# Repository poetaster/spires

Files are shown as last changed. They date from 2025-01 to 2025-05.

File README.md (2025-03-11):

# spires
Spires is an arpeggiating synth using time of flight sensors to drive one or more digital oscillators. The processor used is either and arduino nano or and LGTBF328P.

Tremello is implemented with a simple LDR. 

## Modes

The default program reproduces the modes. Holding the encoder button depressed and turning choses a mode, in the traditional order Ionian, Dorian, Phrygian, Lydian, Mixolodian, Aeolian, Locrian. Pressing the encoder button in this program changes the root, from C to B. So you can play all the modes in any key.

The remaining programs are composed to selected scales.  The programs:
1. ragas
2. various historical europeans
3. some more exotics (geographical as well as cultural)
4. pentatonics from diverse cultures
5. hexatonics 

In all a bunch of scale material :)

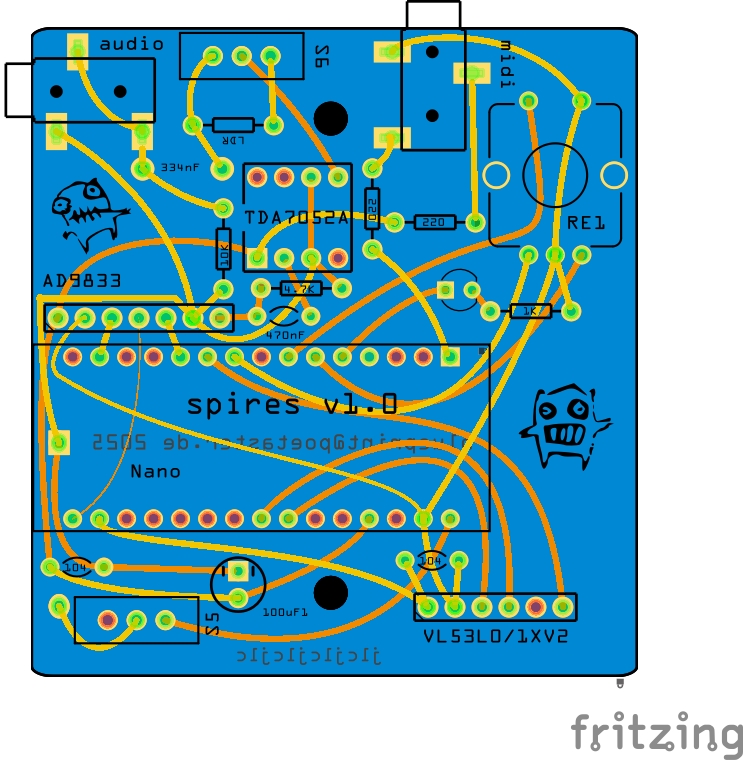
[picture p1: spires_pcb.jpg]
pcb view

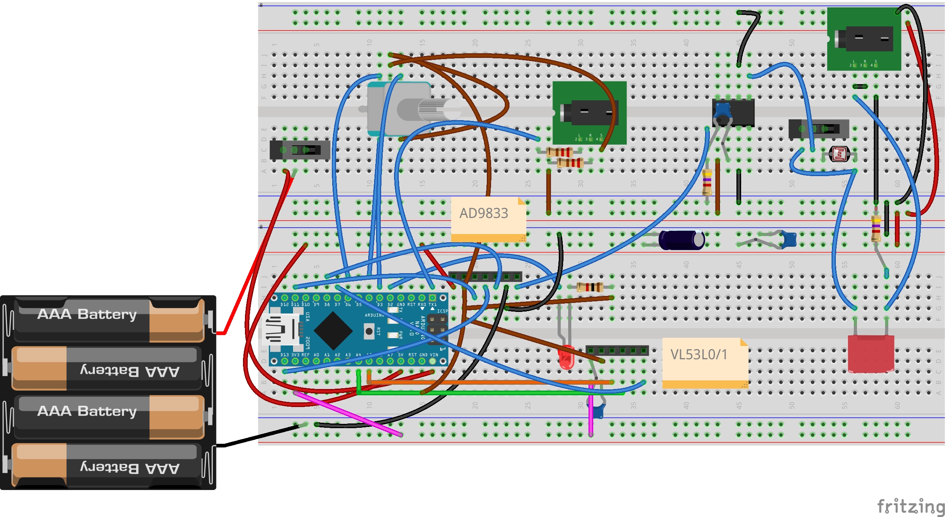
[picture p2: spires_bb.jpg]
breadboard view

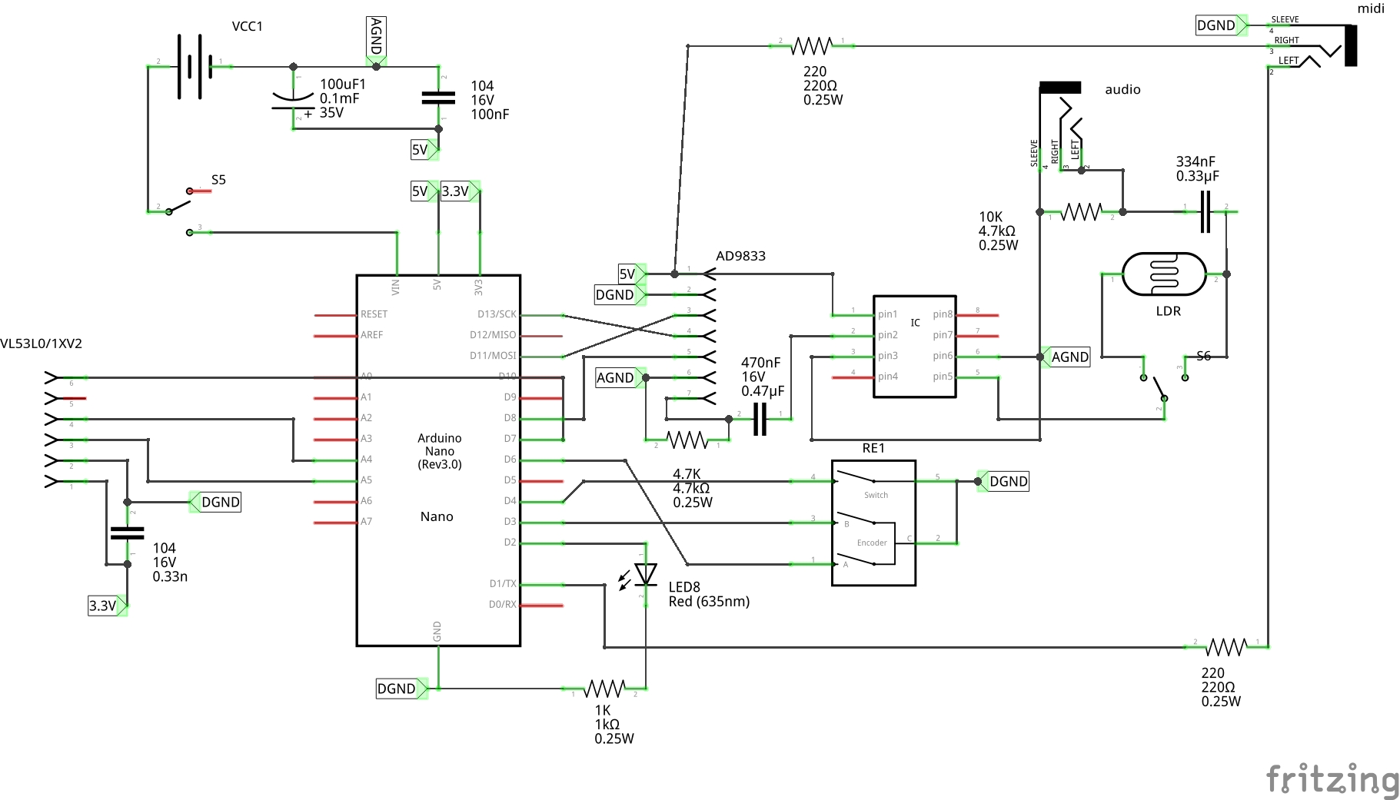
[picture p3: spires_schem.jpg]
schematic view


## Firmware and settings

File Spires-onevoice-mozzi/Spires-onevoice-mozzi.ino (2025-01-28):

/*
  Spires is copyright 2024, Mark Washeim blueprint@poetaster.de
  GPLv3
*/

#include <Wire.h>
#include <VL53L0X.h>
#include <RotaryEncoder.h>

// MOZZI
#define MOZZI_CONTROL_RATE 256  // Hz, powers of 2 are most reliable
#include <Mozzi.h>
#include <Oscil.h>
#include <tables/cos2048_int8.h>  // table for Oscils to play
#include <EventDelay.h>
#include <mozzi_rand.h>
#include <mozzi_midi.h>
#include <Smooth.h>
// audio oscils

Oscil<COS2048_NUM_CELLS, MOZZI_AUDIO_RATE> aCarrier(COS2048_DATA);
Oscil<COS2048_NUM_CELLS, MOZZI_AUDIO_RATE> aModulator(COS2048_DATA);
Oscil<COS2048_NUM_CELLS, MOZZI_AUDIO_RATE> aModDepth(COS2048_DATA);

// for scheduling note changes in updateControl()
EventDelay kNoteChangeDelay;

UFix<8, 8> ratio;          // unsigned int with 8 integer bits and 8 fractional bits
UFix<24, 8> carrier_freq;  // unsigned long with 24 integer bits and 8 fractional bits

// for random notes
const UFix<7, 0> octave_start_note = 42;

// END MOZZI


bool debug = true;


// on the long ec11 these are swapped A 19, B 18
const int encoderA_pin = 2;
const int encoderB_pin = 3;
const int encoderSW_pin = 5;
// variables for UI state management
int encoder_pos_last = 0;
int encoder_delta = 0;


// encoder
RotaryEncoder encoder(encoderB_pin, encoderA_pin, RotaryEncoder::LatchMode::FOUR3);
void checkEncoderPosition() {
  encoder.tick();   // call tick() to check the state.
}

/* these come from rampart bytebeats */
int enc_offset = 1; // changes direction
int enc_delta; // which direction
//for program switching
int prog = 1;
int bank = 1;
int pb1 = 1;
int pb1total = 8;
int pb2 = 1;
int pb2total = 28;
int pb3 = 1;
int pb3total = 20;

int numProg = 8;



/* AUDIO */
const float ContToFreq[63] PROGMEM = {29.14, 30.87, 32.70, 34.65, 36.71, 38.89, 41.20, 43.65, 46.25, 49.00, 51.91, 55.00,
                                      58.27, 61.74, 65.41, 69.30, 73.42, 77.78, 82.41, 87.31, 92.50, 98.00, 103.83, 110.00,
                                      116.54, 123.47, 130.81, 138.59, 146.83, 155.56, 164.81, 174.61, 185.00, 196.00, 207.65, 220.00,
                                      233.08, 246.94, 261.63, 277.18, 293.66, 311.13, 329.63, 349.23, 369.99, 392.00, 415.30, 440.00,
                                      466.16, 493.88, 523.25, 554.37, 587.33, 622.25, 659.25, 698.46, 739.99, 783.99, 830.61, 880.00,
                                      932.33, 987.77, 1046.50
                                     };
// AD9833 Waveform Module
const int SINE = 0x2000;                    // Define AD9833's waveform register value.
const int SQUARE = 0x2028;                  // When we update the frequency, we need to
const int TRIANGLE = 0x2002;                // define the waveform when we end writing.
const float refFreq = 25000000.0;           // On-board crystal reference frequency
float freq_init1 = 440.0;                    // Initial frequency for Generator 1
float freq_init2 = 442.0;                    // Initial frequency for Generator 2
float freq_target1 = 440.0;                 // Target frequency for Generator 1
float freq_target2 = 442.0;                 // Target frequency for Generator 2
float freq_offset = 1; //4 / 3;

float volume = 1000;  // volume for our machine

// Table with note symbols, used for display
const char *IndexToNote[] = {"C-", "C#", "D-", "D#", "E-", "F-", "F#", "G-", "G#", "A-", "A#", "B-"};

// Tables with frequencies from scales around the world
#include "scales.h"

#define BASE_NOTE_FREQUENCY  16.3516 // C-0, Core of note/cent offset calculations, keep it accurate
// Definition of generated frequency range

signed char note_target = 47; //A-4, 440Hz
#define NOTE_CALCULATION_OFFSET 10 //base note for calculation is C-0, but note table starts from A#0 

float noteIndex;

/* END AUDIO */


// The Arduino pin connected to the XSHUT pin of each sensor.
const uint8_t xshutPins[2] = {6, 7};

int led = 10; // for the vactrol
//  analogReference(DEFAULT);  // 5v

// The number of sensors in your system.
const uint8_t sensorCount = 2;
VL53L0X sensors[sensorCount];

// variables for runtime control
bool up;
bool cont = true;
bool continuous = false;
float lastVol = 99;
float currentDepth = 9;
bool flutter = false;

void setup()
{

  //while (!Serial) {}
  Serial.begin(115200);
  //Wire1.setSDA(14); These are for the pi pico
  //Wire1.setSCL(15);
  //Wire.setSDA(0);
  //Wire.setSCL(1);
  
  Wire.begin();
  Wire.setClock(400000); // use 400 kHz I2C

  
  // setup the sensors
  // Disable/reset all sensors by driving their XSHUT pins low.
  for (uint8_t i = 0; i < sensorCount; i++)
  {
    pinMode(xshutPins[i], OUTPUT);
    digitalWrite(xshutPins[i], LOW);
  }

  // Enable, initialize, and start each sensor, one by one.
  for (uint8_t i = 0; i < sensorCount; i++)
  {
    // Stop driving this sensor's XSHUT low. This should allow the carrier
    // board to pull it high. (We do NOT want to drive XSHUT high since it is
    // not level shifted.) Then wait a bit for the sensor to start up.
    pinMode(xshutPins[i], INPUT);
    delay(10);

    sensors[i].setTimeout(500);
    if (!sensors[i].init())
    {
      Serial.print("Failed to detect and initialize sensor ");
      Serial.println(i);
      while (1);
    }

    // Each sensor must have its address changed to a unique value other than
    // the default of 0x29 (except for the last one, which could be left atSerial.println(freq_init1);
    // the default). To make it simple, we'll just count up from 0x2A.
    sensors[i].setAddress(0x2A + i);
    sensors[i].startContinuous(50);
    sensors[i].setMeasurementTimingBudget(70000); //  adjust this value to move to slower note slurs/jumps

  }
  
  //pinMode(23, OUTPUT); // thi is to switch to PWM pi pico for power to avoid ripple noise
  //digitalWrite(23, HIGH);

  // ENCODER
  pinMode(encoderA_pin, INPUT_PULLUP);
  pinMode(encoderB_pin, INPUT_PULLUP);
  pinMode(5, INPUT_PULLUP);
  attachInterrupt(digitalPinToInterrupt(encoderA_pin), checkEncoderPosition, CHANGE);
  attachInterrupt(digitalPinToInterrupt(encoderB_pin), checkEncoderPosition, CHANGE);
  
  //sensors[1].setSignalRateLimit(0.1);
  // increase laser pulse periods (defaults are 14 and 10 PCLKs)
  // sensors[1].setVcselPulsePeriod(VL53L0X::VcselPeriodPreRange, 18);
  //sensors[1].setVcselPulsePeriod(VL53L0X::VcselPeriodFinalRange, 14);
  //
  //sensors[0].setMeasurementTimingBudget(70000);
  //sensors[1].setMeasurementTimingBudget(70000);
  
  Serial.println(sensors[0].readRangeSingleMillimeters());
  //analogWrite(4, 255);

  // mozzi setup
  ratio = 3;
  kNoteChangeDelay.set(200);  // note duration ms, within resolution of MOZZI_CONTROL_RATE
  aModDepth.setFreq(13.f);    // vary mod depth to highlight am effects
  randSeed();                 // reseed the random generator for different results each time the sketch runs
  startMozzi();

  if (debug) {
    Serial.println("end setup");
  }


}


int steps = 4;

void updateControl() {

  

  // set play mode 0 play 1 edit patterns, 3 FX?
  /*
  if (encoder_push_millis > 0 ) {
    if ((now - encoder_push_millis) > 25 && ! encoder_delta ) {
      if ( !encoder_held ) {
        encoder_held = true;
        display_mode = display_mode+1;
        if ( display_mode > 2) { // switched back to play mode
          display_mode = 0;
          //configure_sequencer();
        }
      }
    }

    if (step_push_millis > 0) { // we're pushing a step key too
      if (encoder_push_millis < step_push_millis) {  // and encoder was pushed first
        //strcpy(seq_info, "saveseq");
      }
    }
  }*/




}

AudioOutput updateAudio() {
  auto mod = UFix<8, 0>(128 + aModulator.next()) * UFix<8, 0>(128 + aModDepth.next());
  return MonoOutput::fromSFix(mod * toSFraction(aCarrier.next()));
}

// second core setup
// second core dedicated to sample processing
void setup1() {
  delay (1000); // wait for main core to start up perhipherals
  
}

// second core calculates samples and sends to DAC
void loop1() {
float temp1;
  int temp2;
  float voltemp;
  Serial.println("Update control");
  if (sensors[0].timeoutOccurred()) {
    Serial.print(" TIMEOUT");
  }

  volume = sensors[0].readRangeContinuousMillimeters();

  Serial.println(volume);
  if (volume < 8190.00) {
    //if (debug )    Serial.println(volume);
    // alwasy adjust volume as fast as possible and don't continue loop until it's finished.
    volume = map(volume, 50, 1300, 255, 1);

    if (volume > 255) volume = 255;
    if (volume < 1 ) volume = 1;
    if (debug )    Serial.println( lastVol);
    //if (debug ) Serial.print(" - ");

    //Tremello(); //
    if (! flutter) {
      //flutter = GlideVolume( volume , lastVol );
    }
    //currentDepth = volume;
    lastVol = volume;
     ratio = volume;
  }

  freq_target2 = sensors[1].readRangeContinuousMillimeters();
  
  if (freq_target2  < 1300 ) {
    if ( ! continuous ) {
      temp2 = int(map(freq_target2, 50, 1300, 28, 0));
    } else {
      temp2 = map(freq_target2, 50, 1300, 780, 420);
    }
    //if (debug) Serial.print("freq:");
    //if (debug )  Serial.println(temp2);
  }

  switch (prog) {
    case 1:
      temp1 = pgm_read_float( &IndexToFreq[temp2 ]);
      break;
    case 2:
      temp1 = pgm_read_float( &BayatiToFreq[temp2 ]);
      break;
    case 3:
      temp1 = pgm_read_float( &nawaAtharToFreq[temp2]);
      break;
    case 4:
      temp1 = pgm_read_float( &farafahzaToFreq[temp2 ]);
      break;
    case 5:
      temp1 = pgm_read_float( &nikrizToFreq[temp2 ]);
      break;
    case 6:
      temp1 = pgm_read_float( &phrygianToFreq[temp2 ]);
      break;
    case 7:
      temp1 = pgm_read_float( &romaMinorToFreq[temp2 ]);
      break;
    case 8:
      temp1 = pgm_read_float( &partch1ToFreq[temp2 ]);
      break;
  }


  // here we either glide up or down
  if ( temp1 < 1600  && temp1 > 30 && continuous == false) {
    if (freq_init1 > temp1) {
      cont = GlideFreq(freq_init1, temp1, false);

    } else if (freq_init1 < temp1) {
      cont = GlideFreq(freq_init1, temp1, true);
    }
    freq_init1 = temp1;
  } else if (temp2 < 800  && temp2 > 100 && continuous == true ) { //&& abs(freq_init1 - temp2) > 5 ) {
    if (freq_init1 > temp2) {
      cont = GlideContinuous(freq_init1, temp2, false);

    } else if (freq_init1 < temp2) {
      cont = GlideContinuous(freq_init1, temp2, true);
    }
    freq_init1 = temp2;
  }


  encoder.tick();
  
  int encoder_pos = encoder.getPosition();
  if ( (encoder_pos != encoder_pos_last )) {
    encoder_delta = encoder_pos - encoder_pos_last;
    prog = constrain(encoder_pos, 1, numProg );
    Serial.println(encoder_pos);
  }

}

void loop()
{
    audioHook();
}

// END LOOP

// Function to glide notes up/down
bool GlideFreq(float from, float too, bool up) {
   Serial.println("Glide");
  //make sure we complete the glides before the loop proceeds
  cont = false;
  if (up) {
    while (from < too) {
      carrier_freq = from;
      auto mod_freq = carrier_freq * ratio;
      aCarrier.setFreq(carrier_freq);
      aModulator.setFreq(mod_freq);
      from = from + 0.3;
      }
  } else {
    while (from > too) {
      carrier_freq = from;
      auto mod_freq = carrier_freq * ratio;
      aCarrier.setFreq(carrier_freq);
      aModulator.setFreq(mod_freq);
      from = from - 0.3;

    }
    // complete since while may exit early

  }


  return true;
}
// Function to glide notes up/down
bool GlideContinuous(float from, float too, bool up) {
  //make sure we complete the glides before the loop proceeds
  cont = false;
  if (up) {
    while (from < too) {
      //AD[0].setFrequency(from);
      //AD[1].setFrequency(from * freq_offset);
      from = from + 0.1;

    }
    // complete since while may exit early
    //AD[0].setFrequency(too);
    //AD[1].setFrequency(too * freq_offset);

  } else {
    while (from > too) {
      //AD[0].setFrequency(from);
      //AD[1].setFrequency(from * freq_offset);
      from = from - 0.1;

    }
    // complete since while may exit early
    //AD[0].setFrequency(too);
    //AD[1].setFrequency(too * freq_offset);
  }
  return true;
}



// Function to glide volume up/down
bool GlideVolume(float from, float too) {
  flutter = true;
  //make sure we complete the glides before the loop proceeds
  float ft = from;

  if (from < too) {
    while (ft < too) {
      //analogWrite(4, from);
      ft = ft + 1;
      //MCP.setValue(from);
      //pot.increase(1);

    }

  } else {
    while (ft > too) {
      //analogWrite(4, from);
      ft = ft - 1;
      //MCP.setValue(from);
      //pot.decrease(1);


    }
  }
  return false;
}
// Function to glide volume up/down
void Tremello() {
  //make sure we complete the glides before the loop proceeds
  if (lastVol < ( 99 - currentDepth) ) {
    lastVol = lastVol + 1;
    //pot.increase(1);

  } else {
    lastVol = lastVol - 1;
    //pot.decrease(1);
  }
  if (debug )    Serial.println( lastVol);
}

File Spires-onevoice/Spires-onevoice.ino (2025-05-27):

/*
  Spires is copyright 2024, Mark Washeim blueprint@poetaster.de
  GPLv3



*/
#include <SPI.h>
#include <Wire.h>
#include <VL53L0X.h>
#include <MIDI.h>
#include <Midier.h>
#include <math.h>
#include <util/crc16.h>
#include "AD9833.h"

// # define ENCODER_DO_NOT_USE_INTERRUPTS
#include <EncoderButton.h>

// some midier setup

MIDI_CREATE_INSTANCE(HardwareSerial, Serial, MIDI);


const midier::Degree scaleDegrees[] = { 1, 2, 3, 4, 5, 6, 7, 8, 9, 10, 11, 12, 13, 14, 15, 16, 17, 18, 19, 20, 21 };
const midier::Note roots[] = {
  midier::Note::C, midier::Note::D,  midier::Note::E, midier::Note::F, midier::Note::G, midier::Note::A, midier::Note::B
};

midier::Mode mode;
int scaleRoot = 0; // start at c, yawn.

int currentMode[21];

void initScales() {
  // iterate over all root notes
  const midier::Mode mode = midier::Mode::Ionian;
  for (auto note : roots)
  {
    // play the major chord
    makeScale(note, mode);
  }
}
void makeScale(midier::Note root, midier::Mode mode) {

  // the root note of the scale
  const midier::Note scaleRoot = root;

  // we are playing ionian mode which is the major scale
  // if you are not familiar with modes, just know that "ionian" is the major scale and "aeolian" is the minor scale
  //const midier::Mode mode = midier::Mode::Ionian;


  for (midier::Degree scaleDegree : scaleDegrees)
  {
    // find out the interval to be added to the root note for this chord degree and chord quality
    const midier::Interval interval = midier::scale::interval(mode, scaleDegree);

    // calculate the note of this chord degree
    const midier::Note note = scaleRoot + interval;
    currentMode[ scaleDegree - 1 ] = midier::midi::number(note, 2);


  }
  //Serial.println();
}


bool debug = false;
// variables for runtime control
bool up;
bool cont = true;
volatile float lastvol = 255;
unsigned int lastPos;
bool continuous = false;
bool sine = true;

// freq to midi
static const uint32_t midi_note_at_zero_volts = 12;
static const float semitones_per_octave = 12.0f;
static const float volts_per_semitone = 1.0f / semitones_per_octave;
static const float a4_frequency = 440.0f;
static const uint32_t a4_midi_note = 69;

int led = 2; // for display led
// default works fine


/*
  Converts a note frequency to the closest corresponding MIDI
  note number.
  Adapted from https://gist.github.com/francoisgeorgy/d155f4aa5e8bd767504c2b43e1ba2902
*/
uint32_t frequency_to_midi_note(float frequency) {
  float note = 69.0f + logf(frequency / a4_frequency) / logf(2.0f) * semitones_per_octave;
  return ceil(note);
}

float midi_note_to_frequency(uint32_t midi_note) {
  float semitones_away_from_a4 = (float)(midi_note) - (float)(a4_midi_note);
  return powf(2.0f, semitones_away_from_a4 / semitones_per_octave) * a4_frequency;
}

int midiChannel = 1;  // Define which MIDI channel to transmit on (1 to 16).


// need to send note offs :)
void allOff() {
  for (int i = 28; i < 90; i++) {
    if ( ! debug) MIDI.sendNoteOff(i, 0, midiChannel);
  }
}


/* signal generator setup */

unsigned int cSpeed = 200000;
//  each device needs its own select pin.
AD9833 AD[1] =
{
  AD9833(8),
  //AD9833(9)
};  //  4 devices.

/* TOF sensor setup */

// The number of sensors in your system.
const uint8_t sensorCount = 1; // original used two. switched to ldr for volume
// The Arduino pin connected to the XSHUT pin of each sensor.
const uint8_t xshutPins[sensorCount] = {7};

VL53L0X sensors[sensorCount];


// encoder setup
// the a and b + the button pin large encoders are 6,5,4
EncoderButton eb1(3, 6, 4);


/* these come from rampart bytebeats */
int encoder_pos_last = 0;
long encoder_delta = 0;
int enc_offset = 1; // changes direction
int enc_delta; // which direction

// program switching ugh, todo
int prog = 0;
int bank = 0;
int pb1 = 0;
int pb1total = 7;
int pb2 = 0;
int pb2total = 6;
int pb3 = 0;
int pb3total = 6;
int pb4 = 0;
int pb4total = 10;
int pb5 = 0;
int pb5total = 6;
int pb6 = 0;
int pb6total = 7;

int numProg = 41;
int numBank = 6;

// we have to slow it down :)
unsigned long startMillis;
unsigned long currentMillis;
const unsigned long period = 95; // this is the frequency change loop delay

int lastNote;

/* led control vars */
int ledState = LOW;
int blinkTotal = 0;
unsigned long previousMillis ; // = millis();
int intervalLength = 0; // we have three different delay times, so we switch on typte

#include "encoder.h"


/* AUDIO */
const float ContToFreq[63] PROGMEM = {29.14, 30.87, 32.70, 34.65, 36.71, 38.89, 41.20, 43.65, 46.25, 49.00, 51.91, 55.00,
                                      58.27, 61.74, 65.41, 69.30, 73.42, 77.78, 82.41, 87.31, 92.50, 98.00, 103.83, 110.00,
                                      116.54, 123.47, 130.81, 138.59, 146.83, 155.56, 164.81, 174.61, 185.00, 196.00, 207.65, 220.00,
                                      233.08, 246.94, 261.63, 277.18, 293.66, 311.13, 329.63, 349.23, 369.99, 392.00, 415.30, 440.00,
                                      466.16, 493.88, 523.25, 554.37, 587.33, 622.25, 659.25, 698.46, 739.99, 783.99, 830.61, 880.00,
                                      932.33, 987.77, 1046.50
                                     };



#define GEN_DATA    11
// AD9833 Waveform Module
const int SINE = 0x2000;                    // Define AD9833's waveform register value.
const int SQUARE = 0x2028;                  // When we update the frequency, we need to
const int TRIANGLE = 0x2002;                // define the waveform when we end writing.
const float refFreq = 25000000.0;           // On-board crystal reference frequency
float freq_init1 = 440.0;                    // Initial frequency for Generator 1
float freq_init2 = 442.0;                    // Initial frequency for Generator 2
float freq_target1 = 440.0;                 // Target frequency for Generator 1
float freq_target2 = 442.0;                 // Target frequency for Generator 2
float freq_offset = 1; //4 / 3;

// Table with note symbols, used for display
const char *IndexToNote[] = {"C-", "C#", "D-", "D#", "E-", "F-", "F#", "G-", "G#", "A-", "A#", "B-"};

// Tables with frequencies from scales around the world
#include "scales.h"

#define BASE_NOTE_FREQUENCY  16.3516 // C-0, Core of note/cent offset calculations, keep it accurate
// Definition of generated frequency range
#define MIN_GENERATED_FREQ  30.0 // Do not change to lower if you like your speakers
#define MAX_GENERATED_FREQ  1000.0
// Definition of binaural generator setting modes
#define MODE_FREQ_FREQ    0
#define MODE_FREQ_OFFSET  1
#define MODE_NOTE_OFFSET  2
#define MODE_SAVE         3

signed char note_target = 47; //A-4, 440Hz
#define NOTE_CALCULATION_OFFSET 10 //base note for calculation is C-0, but note table starts from A#0 

float noteIndex;

/* END AUDIO */
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

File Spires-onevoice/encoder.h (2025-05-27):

/**
   handle encoder button long press event
*/
void onEb1LongPress(EncoderButton& eb) {

  long ecount = eb.longPressCount();
  if ( ecount > 1 ) {
    if (sine == true) {
      AD[0].setWave(AD9833_TRIANGLE);
      sine = false;
      blinkTotal = 2;
      intervalLength = 300;
    } else {
      AD[0].setWave(AD9833_SINE);
      sine = true;
      blinkTotal = 4;
      intervalLength = 300;
    }
  } else {
    allOff();
    AD[0].setFrequency(10.00, 0);     //  A
  }

  if (debug) {
    Serial.print("button1 longPressCount: ");
    Serial.println(sine);
  }
}
/**
   handle encoder turn with  button pressed
   offsets OCR2A
*/
void onEb1PressTurn(EncoderButton& eb) {

  if (debug == false ) allOff();

  enc_delta = eb.increment();

  bank = bank + enc_delta; // freom main class total
  if ( bank > numBank - 1 ) {
    bank = 0;
  } else if ( bank < 0 ) {
    bank = numBank - 1;
  }

  blinkTotal = (bank + 1) * 2;
  intervalLength = 225;

  if (debug) {
    Serial.print("eb1 press inc by: ");
    Serial.println(enc_delta);
    Serial.print("enc_offset is: ");
    Serial.println(enc_offset);
  }
}

/**
   handle encoder turn with  button pressed
*/
void onEb1Clicked(EncoderButton& eb) {

  // if ( debug == false )  MIDI.sendNoteOff(frequency_to_midi_note(lastNote), 0, midiChannel);//allOff();

  // set which bank to select formulas from
  int type = eb.clickCount();

  if (bank == 0 ) {

    scaleRoot += 1;
    if (scaleRoot > 6) scaleRoot = 0;
    blinkTotal = 2;
    intervalLength = 150;
  } else {
    if (type == 1 ) {
      continuous = true;
      cSpeed = 50000;
      blinkTotal = 2;
      intervalLength = 100;
    }
    if (type == 2) {
      continuous = false;
      cSpeed = 200000;
      blinkTotal = 4;
      intervalLength = 100;
    }
  }

  if (debug) {
    Serial.print("bank: ");
    Serial.println(eb.clickCount());
  }
  // displayUpdate();
}



/**
   A function to handle the 'encoder' event without button
*/
void onEb1Encoder(EncoderButton& eb) {

  // turn off midi notes
  //if (debug == false) allOff();

  //displayUpdate();
  enc_delta = eb.increment();

  //prog = prog + enc_delta; // freom main class total

  if (bank == 0)
  {
    pb1 = pb1 + enc_delta;
    if (pb1 > pb1total - 1) {
      pb1 = 0;
    } else if (pb1 < 0) {
      pb1 = pb1total - 1;
    }
    prog = pb1;
  }
  else if (bank == 1) {
    pb2 = pb2 + enc_delta;
    if (pb2 > pb2total - 1) {
      pb2 = 0;
    } else if (pb2 < 0) {
      pb2 = pb2total - 1;
    }
    prog = pb2;
  }
  else if (bank == 2) {
    pb3 = pb3 + enc_delta;
    if (pb3 > pb3total - 1) {
      pb3 = 0;
    } else if (pb3 < 0) {
      pb3 = pb3total - 1;
    }
    prog = pb3;
  }
  else if (bank == 3) {
    pb4 = pb4 + enc_delta;
    if (pb4 > pb4total - 1) {
      pb4 = 0;
    } else if (pb4 < 0) {
      pb4 = pb4total - 1;
    }
    prog = pb4;
  }
  else if (bank == 4) {
    pb5 = pb5 + enc_delta;
    if (pb5 > pb5total - 1) {
      pb5 = 0;
    } else if (pb5 < 0) {
      pb5 = pb5total - 1;
    }
    prog = pb5;
  }
  else if (bank == 5) {
    pb6 = pb6 + enc_delta;
    if (pb6 > pb6total - 1) {
      pb6 = 0;
    } else if (pb6 < 0) {
      pb6 = pb6total - 1;
    }
    prog = pb6;
  }


  blinkTotal = (prog + 1) * 2;
  intervalLength = 175;

  if (debug) {
    Serial.print("eb1 incremented by: ");
    Serial.println(eb.increment());
    Serial.print("eb1 position is: ");
    Serial.println(prog);
  }
}

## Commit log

2024-11-22 Add: initial addition of prototype arduino code
2024-11-23 Add: encoder button.
2024-11-25 Add: initial fritzing
    [spires.fzz]
2025-01-06 Mod: size mods, reduce components
    [spires.fzz]
2025-01-06 Mod: size mods, reduce components, add new battery mod
    [spires.fzz]
2025-01-08 Add: 12 bit dac/onevoice
    [spires.fzz]
2025-01-08 Fix: add some methods to try to smooth volume control. actually pointless.
    [Spires-onevoice-mcp4725.ino]
2025-01-25 Add: add the variants with the simple arduino-volume3 lib
2025-01-27 Fix: spires one without digital volume. pcb adding ldr / 386
    [spires.fzz]
2025-01-28 Add: LM additions, new breadboard
    [spires.fzz]
2025-01-30 Fix: 386 layout
    [spires.fzz]
2025-02-12 Fix: set one of the encoder pins to interrupt 3. add continuous back. add button and led behaviours
    [spires.fzz]
2025-02-13 Add: switch continuous and notes mode. modify timers a bit
2025-02-13 Add: bank switching press turn logic, modify led timings
2025-02-13 Add: a bunch more scales, some logic for bank/prog switchin
2025-02-17 Fix: add decoupling cap on VL. set timings and distance to more reasonable levels. reduce delay on prog change led
    [spires.fzz]
2025-02-17 Add: top pcb
    [spires-top.fzz]
2025-02-17 Add: 45 hz filter after the LDR. cleans up led lighting noise.
    [spires.fzz]
2025-02-18 Add: images for readme. complete schematic.
    [spires.fzz]
2025-02-19 Release: version one is ready
    [spires-top.fzz, spires.fzz]
2025-02-27 Fix: prog change off by one. timing/distance
    [Spires-onevoice.ino, encoder.h]
2025-03-05 Fix: add a 100 ms watch timer to ensure we dont update note gliding too often
    [Spires-onevoice.ino]
2025-03-10 Add: add last working production gerbers
    [spires-top_contour.gm1, spires-top_copperBottom.gbl, spires-top_copperTop.gtl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]
2025-03-11 Add: bom
    [spires_bom_csv.csv]
2025-03-11 Fix: add midi note offs to program changes
    [Spires-onevoice.ino, encoder.h]
2025-03-12 Release: last fixes to scales
    [Spires-onevoice.ino, encoder.h]
2025-03-12 Cleanup: move gerbers
    [spires-top_contour.gm1, spires-top_copperBottom.gbl, spires-top_copperTop.gtl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]
2025-05-17 Fix: add 1 second press for midi note off, and 2 seconds for waveform change
    [spires.fzz]
2025-05-17 Fix: add a 10Hz freq setting on all off to silence the osc.
    [Spires-onevoice.ino, encoder.h]
2025-05-18 Fix: remove the noteoffs on scale change! add noteoff/freq 10 to distance between 850-1300 mm
    [Spires-onevoice.ino, encoder.h]
2025-05-27 Fix: move led lights to loop timer
    [Spires-onevoice.ino, encoder.h]
2026-03-29 [Fix] add median and adjust distance to 50 cm for better accuracy.
